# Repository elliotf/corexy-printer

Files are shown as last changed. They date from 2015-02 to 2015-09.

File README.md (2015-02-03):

# corexy-printer

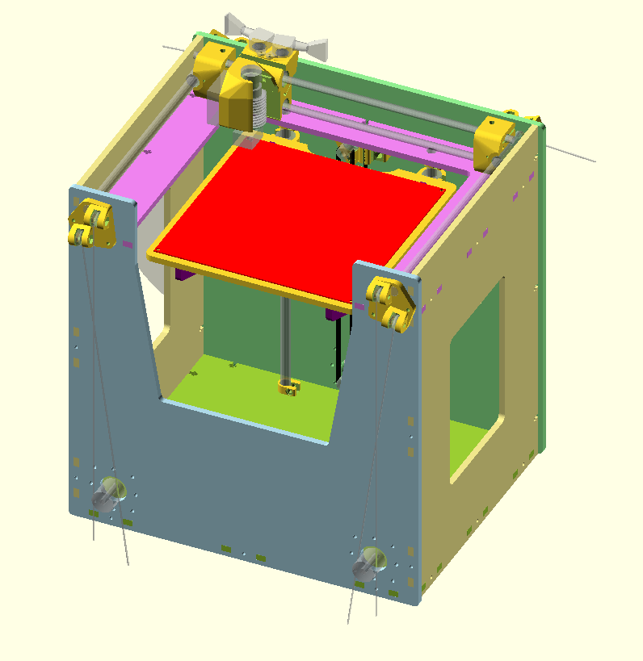
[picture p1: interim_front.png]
rendered picture of printer


An attempt at a compact, flexible, parametric corexy printer design that can be almost entirely lasercut.

The printer at http://audiots.wordpress.com is beautiful and inspired me to create a more unique take on the coreXY reference implementation.

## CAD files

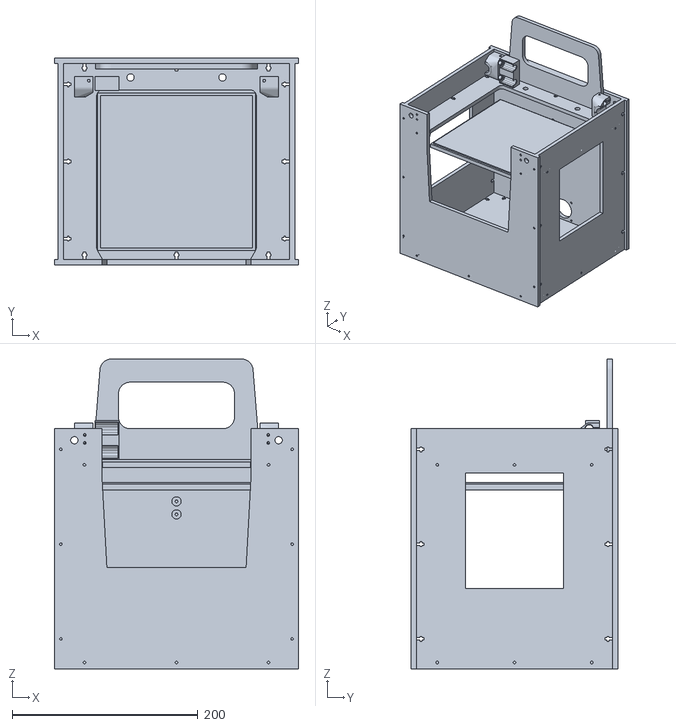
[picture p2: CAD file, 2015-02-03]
assembly.stl
263.0 x 223.1 x 333.9

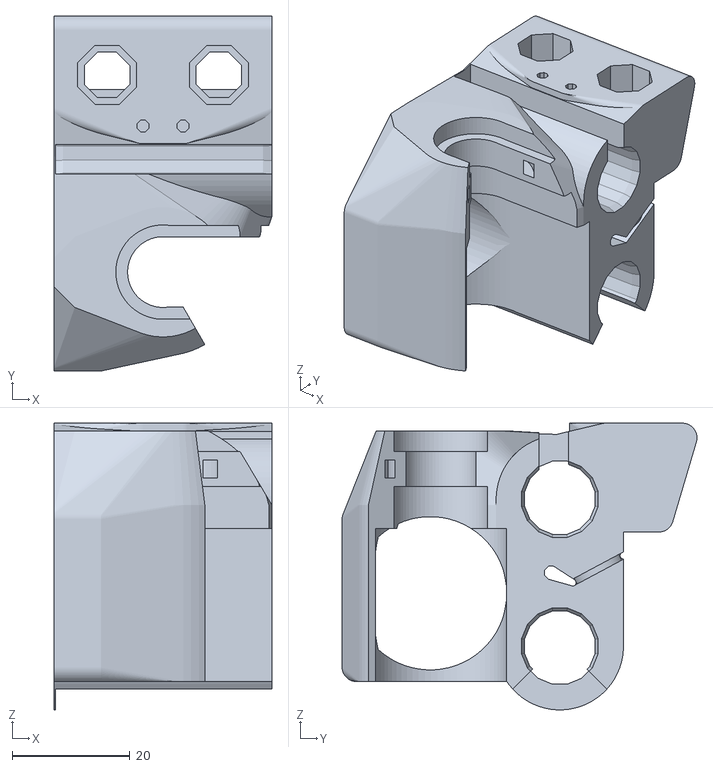
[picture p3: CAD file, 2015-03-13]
parts/x-carriage.stl
37.0 x 60.3 x 48.7

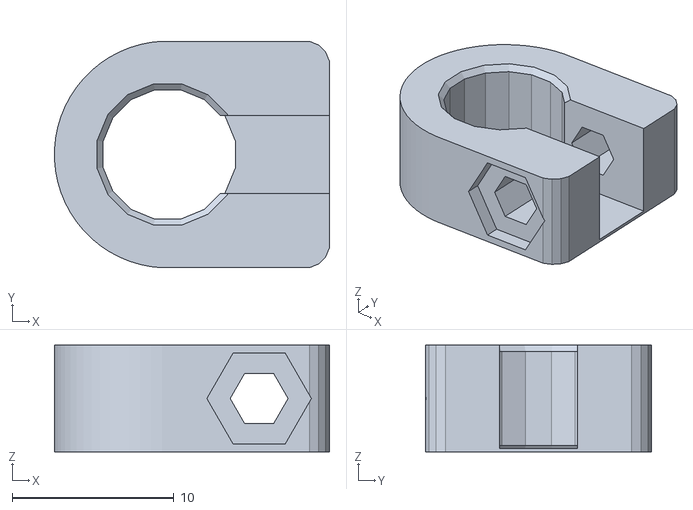
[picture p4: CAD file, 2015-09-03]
rod_clamp.stl
17.0 x 14.0 x 6.60

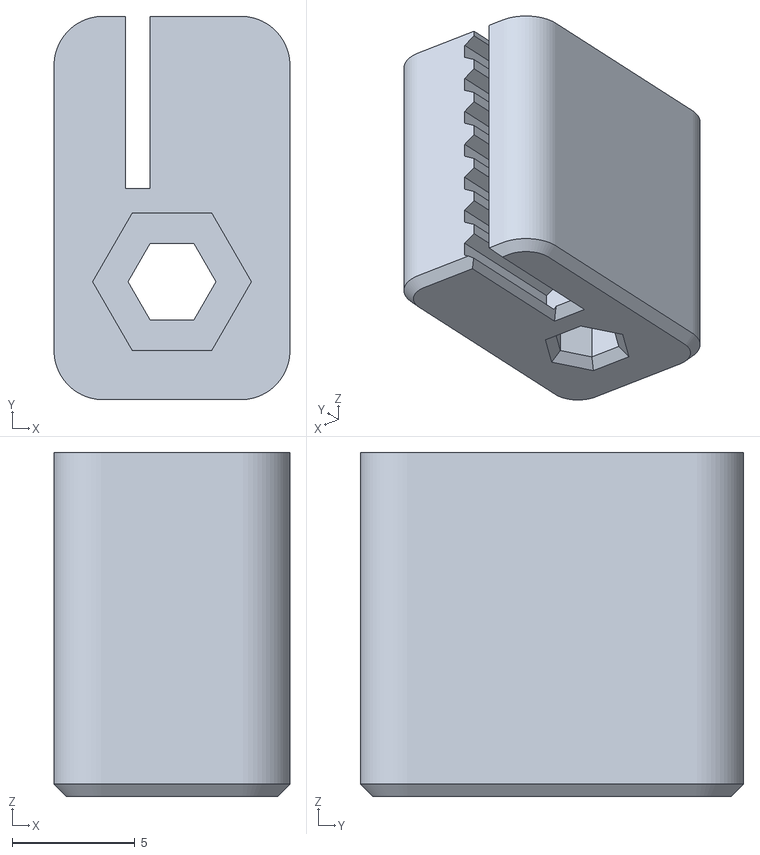
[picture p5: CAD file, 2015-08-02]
belt_tensioner.stl
9.60 x 15.6 x 14.0

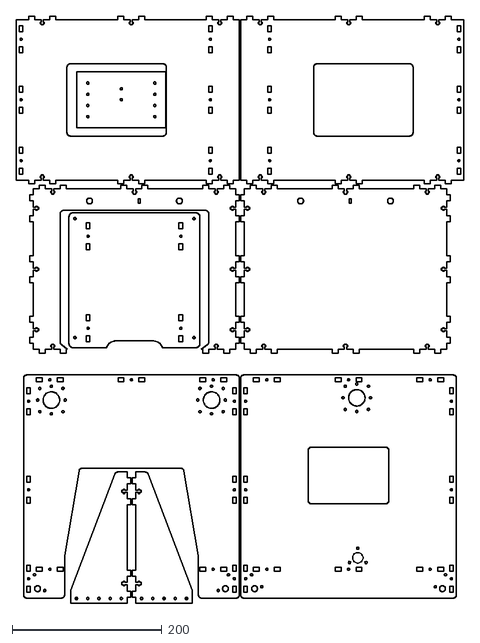
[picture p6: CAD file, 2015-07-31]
laser_cut_sheets.dxf
597.9 x 784.1

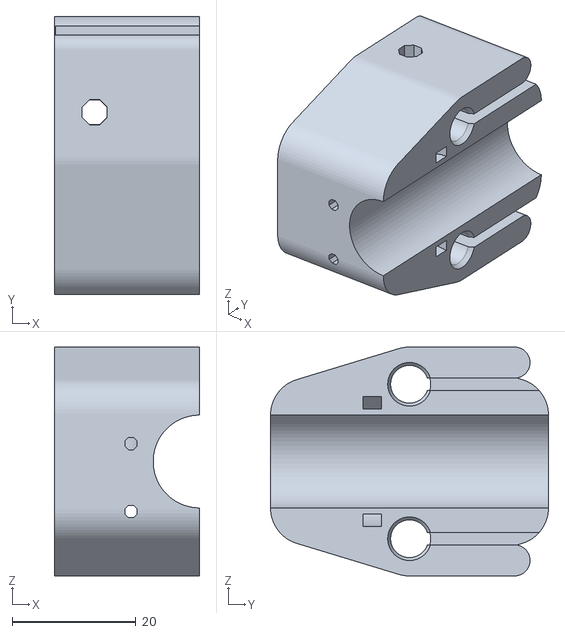
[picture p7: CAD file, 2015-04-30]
y_end.stl
23.5 x 45.0 x 37.0

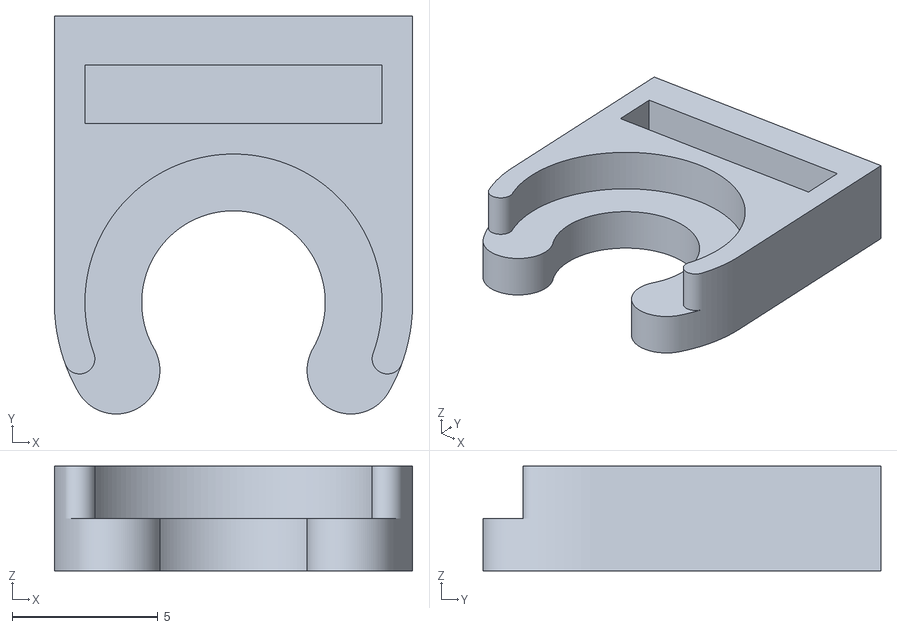
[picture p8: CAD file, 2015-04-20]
bowden_clip-1.75mm-1_8mm.stl
12.3 x 13.7 x 3.60

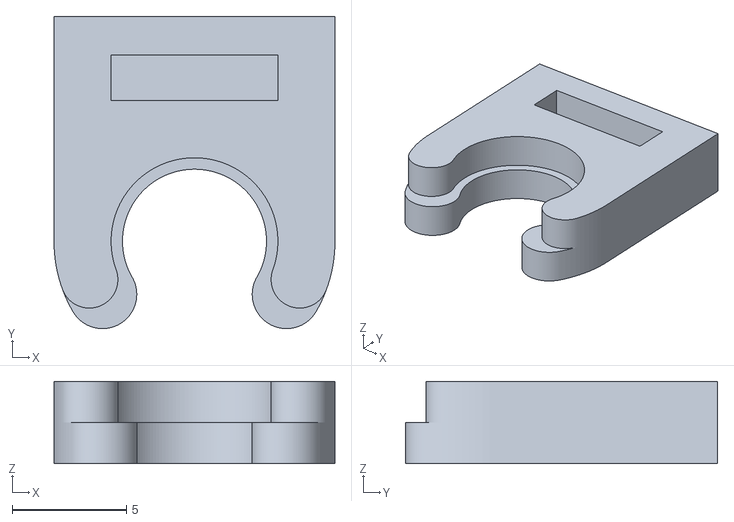
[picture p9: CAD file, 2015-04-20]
bowden_clip-1.75mm-1_8mm-narrow-collar.stl
12.3 x 13.7 x 3.60

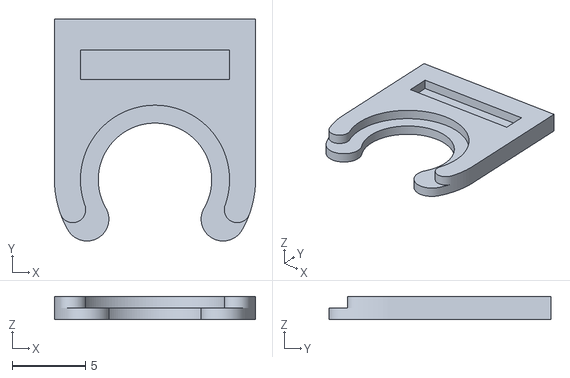
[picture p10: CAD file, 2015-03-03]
e3d-v6-3mm-bowden-clip-0_8mm.stl
13.8 x 15.2 x 1.60

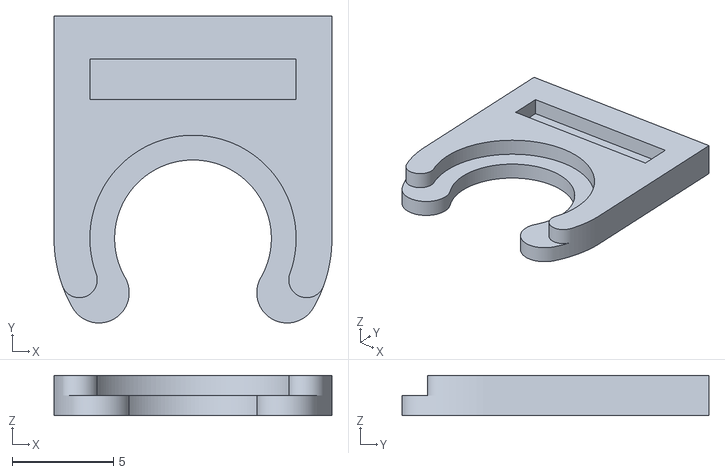
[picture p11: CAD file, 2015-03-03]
e3d-v6-3mm-bowden-clip-1_0mm.stl
13.8 x 15.2 x 2.00

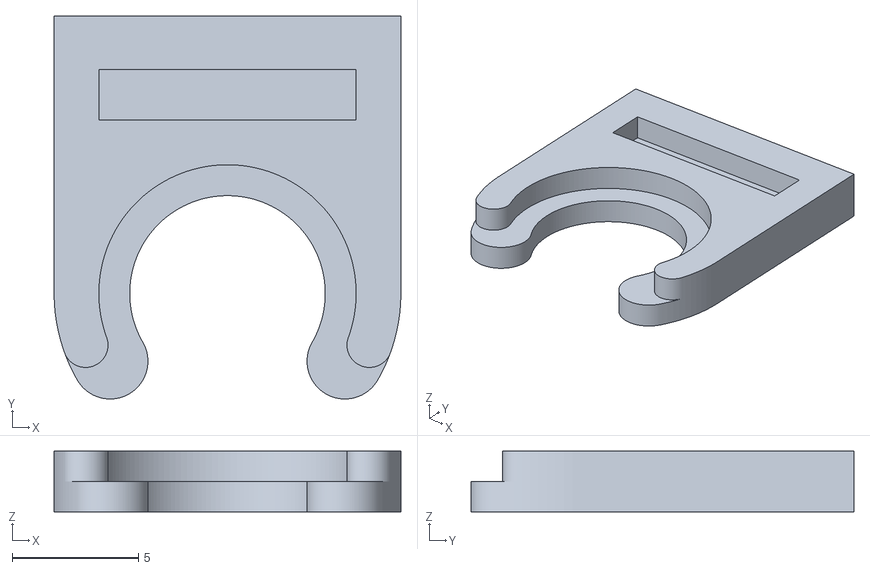
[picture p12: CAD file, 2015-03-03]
e3d-v6-3mm-bowden-clip-1_2mm.stl
13.8 x 15.2 x 2.40

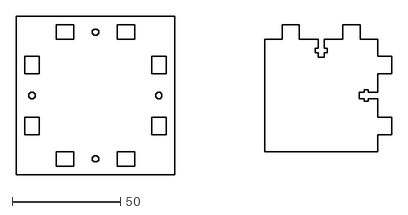
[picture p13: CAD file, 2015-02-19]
laser_cutter_calibration.dxf
173.0 x 73.0

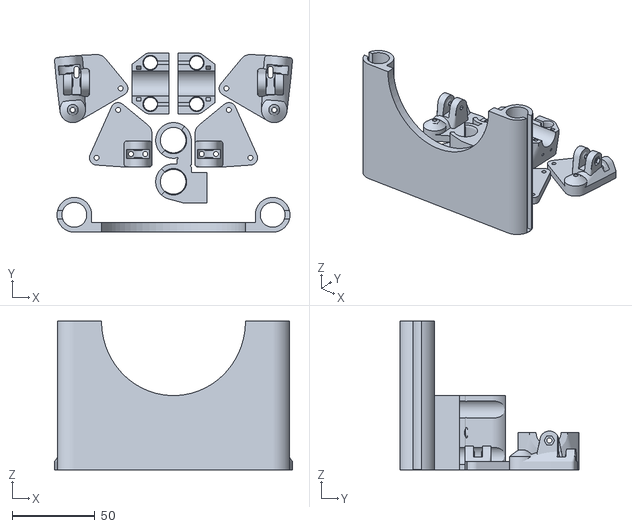
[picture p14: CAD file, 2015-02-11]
print_plate.stl
144.0 x 108.5 x 90.0

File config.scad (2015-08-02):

// All hail whosawhatsis
da6 = 1 / cos(180 / 6) / 2;
da8 = 1 / cos(180 / 8) / 2;

// Screws, nuts
m3_diam = 3.1;
m3_nut_diam  = 5.5 + 0.1;
m3_nut_thickness  = 4;
m3_washer_thickness  = .6;

m5_diam = 5;
m5_nut_diam = 8;
m5_nut_thickness = 5;
m5_washer_thickness  = 1;

m4_diam = 4;
m4_nut_diam = 7;
m4_nut_thickness = 4.5;
m4_washer_thickness  = 1;

bearing_625_diam      = 16;
bearing_625_inner     = 5;
bearing_625_thickness = 5;

approx_pi = 3.14159265359;

laser_cut_kerf = 0.06;

filament_spool_mount_spacer = 4;
filament_spool_inner_diam   = 53;
filament_spool_core_diam    = 93;
filament_spool_outer_diam   = 200;
filament_spool_width        = 71;

// make coordinates more communicative
left    = -1;
right   = 1;
front   = -1;
rear    = 1;
top     = 1;
bottom  = -1;

x = 0;
y = 1;
z = 2;

resolution = 16;
resolution = 64;

extrusion_width  = 0.5;
extrusion_height = 0.2;
min_material_thickness = extrusion_width*2;
wall_thickness         = extrusion_width*4;
rounded_diam           = 4;

// material dimensions
zip_tie_width = 3;
zip_tie_thickness = 2;
line_diam = .5;
line_cube = [line_diam,line_diam,line_diam];

// Printer size
build_x = 200;
build_y = 200;
build_z = 200;

build_x = 150;
build_y = 150;
build_z = 150;

z_belt_clamp_width = 14;

/*
build_x = 100;
build_y = 50;
build_z = 25;

build_x = 100;
build_y = 100;
build_z = 100;
*/

belt_total_thickness = 1.38;
belt_tooth_depth     = 0.75;
belt_thickness       = belt_total_thickness - belt_tooth_depth;
belt_thickness       = 1;
belt_width           = 6; // FIXME: make correct

belt_tooth_pitch   = 2;
num_teeth_to_clamp = 7;
belt_clamp_depth   = belt_width + m3_nut_diam + wall_thickness*1.5 + 1;
belt_clamp_width   = m3_nut_diam + wall_thickness*2;
belt_clamp_height  = num_teeth_to_clamp*belt_tooth_pitch;
z_belt_anchor_height       = belt_clamp_height*1.5;
z_belt_anchor_hole_spacing = z_belt_anchor_height/2;

z_idler_pulley_bearing_retainer_rim_thickness     = 1;
z_idler_pulley_bearing_retainer_thickness         = bearing_625_thickness + z_idler_pulley_bearing_retainer_rim_thickness;

filament_diam = 3;

hotend_diam                = 16;
hotend_groove_diam         = 12;
hotend_groove_height       = 4.6;
hotend_height_above_groove = 5;
hotend_len                 = 63;
hotend_clamped_height      = hotend_groove_height + hotend_height_above_groove;
hotend_len_below_groove    = hotend_len - hotend_clamped_height;
hotend_clearance   = 0.15;

// jhead
hotend_height_above_groove = 4.8;
hotend_groove_height = 4.6;

// e3d v6
hotend_height_above_groove = 3.7;
hotend_groove_height = 6;

// e3d v6 bowden heatsink mount
hotend_len                 = 65;
hotend_height_above_groove = 7;
hotend_height_below_groove = 3;
hotend_groove_height = 6;
hotend_diam = 22.4;
hotend_heatsink_diam = 22.4;
hotend_nozzle_to_bottom_fin = 20;
hotend_nozzle_to_top_fin = 46;
hotend_heatsink_height = 26;
hotend_dist_to_heatsink_bottom = 46;
hotend_dist_to_heatsink_top = hotend_dist_to_heatsink_bottom - hotend_heatsink_height;
hotend_mount_diam  = 16;
hotend_groove_diam = 12;

tuner_hole_to_shoulder = 22.5;
wire_hole_diam = 2;

tuner_thin_diam = 6;
tuner_thin_len_past_hole = 5;
tuner_thin_len = tuner_hole_to_shoulder + tuner_thin_len_past_hole;
tuner_thin_pos = tuner_hole_to_shoulder/2-tuner_thin_len_past_hole/2;

thick_diam = 10;
thick_len = 10;
thick_pos = tuner_hole_to_shoulder-thick_len+thick_len/2;

tuner_body_diam = 15;
tuner_body_thickness = 9;
tuner_body_square_len = 10;
tuner_body_pos = -tuner_hole_to_shoulder-tuner_body_thickness/2;

tuner_anchor_screw_hole_thickness = 2;
tuner_anchor_screw_hole_diam = 2;
tuner_anchor_screw_hole_width = 2;
tuner_anchor_screw_hole_pos_x = tuner_body_pos+tuner_body_thickness/2-tuner_anchor_screw_hole_thickness/2;
tuner_anchor_screw_hole_pos_y = -tuner_body_diam/2;
tuner_anchor_screw_hole_pos_z = -tuner_body_diam/2;

// Linear bearings and rods
// should record bearing groove offset, depth, width

// lm10uu, M10 rods
lm10uu_bearing_diam = 19;
lm10uu_bearing_len  = 29;
lm10uu_bearing_groove_spacing = 0;
lm10uu_bearing_groove_width = 0;
lm10uu_bearing_groove_depth = 0;
lm10uu_rod_diam = 10;

// lm8uu, M8 rods
lm8uu_bearing_diam = 15;
lm8uu_bearing_len  = 24;
lm8uu_bearing_groove_spacing = 0;
lm8uu_bearing_groove_width = 0;
lm8uu_bearing_groove_depth = 0;
lm8uu_rod_diam = 8;

// lm8luu, M8 rods
lm8luu_bearing_diam = 15;
lm8luu_bearing_len  = 45;
lm8luu_bearing_groove_spacing = 0;
lm8luu_bearing_groove_width = 0;
lm8luu_bearing_groove_depth = 0;
lm8luu_rod_diam = 8;

// bronze bushings, M8 rods
bronze_bearing_diam = 12;
bronze_bearing_len  = 15;
//bronze_bearing_len  = 30;
bronze_bearing_groove_spacing = 0;
bronze_bearing_groove_width = 0;
bronze_bearing_groove_depth = 0;
bronze_rod_diam = 8;

// lm6uu, M6 rods
lm6uu_bearing_diam = 12;
lm6uu_bearing_len  = 19;
lm6uu_bearing_groove_spacing = 12.25;
lm6uu_bearing_groove_width = .5;
lm6uu_bearing_groove_depth = .2;
lm6uu_rod_diam = 6;

// lm6luu, M6 rods
lm6luu_bearing_diam = 12;
lm6luu_bearing_len  = 35;
lm6luu_bearing_groove_spacing = 12.25;
lm6luu_bearing_groove_width = .5;
lm6luu_bearing_groove_depth = .2;
lm6luu_rod_diam = 6;

// graphite bearings from robotdigg
graphite_bronze_bearing_diam = 11;
graphite_bronze_bearing_len  = 30;
graphite_bronze_bearing_groove_spacing = 0;
graphite_bronze_bearing_groove_width = 0;
graphite_bronze_bearing_groove_depth = 0;
graphite_bronze_rod_diam = 8;

bearing_diam           = lm10uu_bearing_diam;
bearing_len            = lm10uu_bearing_len;
bearing_groove_spacing = lm10uu_bearing_groove_spacing;
bearing_groove_width   = lm10uu_bearing_groove_width;
bearing_groove_depth   = lm10uu_bearing_groove_depth;
rod_diam               = lm10uu_rod_diam;

bearing_diam           = lm8uu_bearing_diam;
bearing_len            = lm8uu_bearing_len;
bearing_groove_spacing = lm8uu_bearing_groove_spacing;
bearing_groove_width   = lm8uu_bearing_groove_width;
bearing_groove_depth   = lm8uu_bearing_groove_depth;
rod_diam               = lm8uu_rod_diam;

/*
bearing_diam           = bronze_bearing_diam;
bearing_len            = bronze_bearing_len;
bearing_groove_spacing = bronze_bearing_groove_spacing;
bearing_groove_width   = bronze_bearing_groove_width;
bearing_groove_depth   = bronze_bearing_groove_depth;
rod_diam               = bronze_rod_diam;

bearing_diam           = lm6uu_bearing_diam;
bearing_len            = lm6uu_bearing_len;
bearing_groove_spacing = lm6uu_bearing_groove_spacing;
bearing_groove_width   = lm6uu_bearing_groove_width;
bearing_groove_depth   = lm6uu_bearing_groove_depth;
rod_diam               = lm6uu_rod_diam;
*/

// if you'd like the x axis to use different rods/bearings
x_bearing_diam           = lm8luu_bearing_diam;
x_bearing_len            = lm8luu_bearing_len;
x_bearing_groove_spacing = lm8luu_bearing_groove_spacing;
x_bearing_groove_width   = lm8luu_bearing_groove_width;
x_bearing_groove_depth   = lm8luu_bearing_groove_depth;
x_rod_diam               = lm8luu_rod_diam;

x_bearing_diam           = lm8uu_bearing_diam;
x_bearing_len            = lm8uu_bearing_len;
x_bearing_groove_spacing = lm8uu_bearing_groove_spacing;
x_bearing_groove_width   = lm8uu_bearing_groove_width;
x_bearing_groove_depth   = lm8uu_bearing_groove_depth;
x_rod_diam               = lm8uu_rod_diam;

x_bearing_diam           = lm6uu_bearing_diam;
x_bearing_len            = lm6uu_bearing_len;
x_bearing_groove_spacing = lm6uu_bearing_groove_spacing;
x_bearing_groove_width   = lm6uu_bearing_groove_width;
x_bearing_groove_depth   = lm6uu_bearing_groove_depth;
x_rod_diam               = lm6uu_rod_diam;

x_bearing_diam           = lm6luu_bearing_diam;
x_bearing_len            = lm6luu_bearing_len;
x_bearing_groove_spacing = lm6luu_bearing_groove_spacing;
x_bearing_groove_width   = lm6luu_bearing_groove_width;
x_bearing_groove_depth   = lm6luu_bearing_groove_depth;
x_rod_diam               = lm6luu_rod_diam;

/*
// if you'd like the x axis to use the default rods/bearings
x_bearing_diam           = bearing_diam;
x_bearing_len            = bearing_len;
x_bearing_groove_spacing = bearing_groove_spacing;
x_bearing_groove_width   = bearing_groove_width;
x_bearing_groove_depth   = bearing_groove_depth;
x_rod_diam               = rod_diam;
*/

// y bearings
y_bearing_diam           = lm8luu_bearing_diam;
y_bearing_len            = lm8luu_bearing_len;
y_bearing_groove_spacing = lm8luu_bearing_groove_spacing;
y_bearing_groove_width   = lm8luu_bearing_groove_width;
y_bearing_groove_depth   = lm8luu_bearing_groove_depth;
y_rod_diam               = lm8luu_rod_diam;

// y bearings
y_bearing_diam           = graphite_bronze_bearing_diam;
y_bearing_len            = graphite_bronze_bearing_len;
y_bearing_groove_spacing = graphite_bronze_bearing_groove_spacing;
y_bearing_groove_width   = graphite_bronze_bearing_groove_width;
y_bearing_groove_depth   = graphite_bronze_bearing_groove_depth;
y_rod_diam               = graphite_bronze_rod_diam;
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

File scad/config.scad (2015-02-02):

// All hail whosawhatsis
da6 = 1 / cos(180 / 6) / 2;
da8 = 1 / cos(180 / 8) / 2;

approx_pi = 3.14159;

laser_cut_kerf = 0.06;

// make coordinates more communicative
left    = -1;
right   = 1;
front   = -1;
rear    = 1;
top     = 1;
bottom  = -1;

x = 0;
y = 1;
z = 2;

resolution = 16;
resolution = 64;

extrusion_width  = 0.5;
extrusion_height = 0.3;

// material dimensions
zip_tie_width = 3;
zip_tie_thickness = 2;
line_diam = .5;
line_cube = [line_diam,line_diam,line_diam];

// Printer size
build_x = 200;
build_y = 200;
build_z = 200;

build_x = 150;
build_y = 150;
build_z = 150;

/*
build_x = 100;
build_y = 100;
build_z = 100;
*/

belt_thickness = 0.5; // FIXME: make correct
belt_width     = 6; // FIXME: make correct

hotend_diam                = 16;
hotend_groove_diam         = 12;
hotend_groove_height       = 4.6;
hotend_height_above_groove = 5;
hotend_len                 = 63;
hotend_clamped_height      = hotend_groove_height + hotend_height_above_groove;
hotend_len_below_groove    = hotend_len - hotend_clamped_height;

// Linear bearings and rods
// should record bearing groove offset, depth, width

// lm10uu, M10 rods
lm10uu_bearing_diam = 19;
lm10uu_bearing_len  = 29;
lm10uu_bearing_groove_spacing = 0;
lm10uu_bearing_groove_width = 0;
lm10uu_bearing_groove_depth = 0;
lm10uu_rod_diam = 10;

// lm8uu, M8 rods
lm8uu_bearing_diam = 15;
lm8uu_bearing_len  = 24;
lm8uu_bearing_groove_spacing = 0;
lm8uu_bearing_groove_width = 0;
lm8uu_bearing_groove_depth = 0;
lm8uu_rod_diam = 8;

// lm8luu, M8 rods
lm8luu_bearing_diam = 15;
lm8luu_bearing_len  = 45;
lm8luu_bearing_groove_spacing = 0;
lm8luu_bearing_groove_width = 0;
lm8luu_bearing_groove_depth = 0;
lm8luu_rod_diam = 8;

// bronze bushings, M8 rods
bronze_bearing_diam = 12;
bronze_bearing_len  = 15;
//bronze_bearing_len  = 30;
bronze_bearing_groove_spacing = 0;
bronze_bearing_groove_width = 0;
bronze_bearing_groove_depth = 0;
bronze_rod_diam = 8;

// lm6uu, M6 rods
lm6uu_bearing_diam = 12;
lm6uu_bearing_len  = 19;
lm6uu_bearing_groove_spacing = 12.25;
lm6uu_bearing_groove_width = .5;
lm6uu_bearing_groove_depth = .2;
lm6uu_rod_diam = 6;

bearing_diam           = lm10uu_bearing_diam;
bearing_len            = lm10uu_bearing_len;
bearing_groove_spacing = lm10uu_bearing_groove_spacing;
bearing_groove_width   = lm10uu_bearing_groove_width;
bearing_groove_depth   = lm10uu_bearing_groove_depth;
rod_diam               = lm10uu_rod_diam;

bearing_diam           = lm8uu_bearing_diam;
bearing_len            = lm8uu_bearing_len;
bearing_groove_spacing = lm8uu_bearing_groove_spacing;
bearing_groove_width   = lm8uu_bearing_groove_width;
bearing_groove_depth   = lm8uu_bearing_groove_depth;
rod_diam               = lm8uu_rod_diam;

/*
bearing_diam           = bronze_bearing_diam;
bearing_len            = bronze_bearing_len;
bearing_groove_spacing = bronze_bearing_groove_spacing;
bearing_groove_width   = bronze_bearing_groove_width;
bearing_groove_depth   = bronze_bearing_groove_depth;
rod_diam               = bronze_rod_diam;

bearing_diam           = lm6uu_bearing_diam;
bearing_len            = lm6uu_bearing_len;
bearing_groove_spacing = lm6uu_bearing_groove_spacing;
bearing_groove_width   = lm6uu_bearing_groove_width;
bearing_groove_depth   = lm6uu_bearing_groove_depth;
rod_diam               = lm6uu_rod_diam;
*/

// if you'd like the z axis to use different rods/bearings
z_bearing_diam           = lm8uu_bearing_diam;
z_bearing_len            = lm8uu_bearing_len;
z_bearing_groove_spacing = lm8uu_bearing_groove_spacing;
z_bearing_groove_width   = lm8uu_bearing_groove_width;
z_bearing_groove_depth   = lm8uu_bearing_groove_depth;
z_rod_diam               = lm8uu_rod_diam;

z_bearing_diam           = lm8luu_bearing_diam;
z_bearing_len            = lm8luu_bearing_len;
z_bearing_groove_spacing = lm8luu_bearing_groove_spacing;
z_bearing_groove_width   = lm8luu_bearing_groove_width;
z_bearing_groove_depth   = lm8luu_bearing_groove_depth;
z_rod_diam               = lm8luu_rod_diam;

/*
z_bearing_diam           = bearing_diam;
z_bearing_len            = bearing_len;
z_bearing_groove_spacing = bearing_groove_spacing;
z_bearing_groove_width   = bearing_groove_width;
z_bearing_groove_depth   = bearing_groove_depth;
z_rod_diam               = rod_diam;
*/

rod_slop = 0.1;

// endstop dimensions
endstop_len = 20;
endstop_width = 6;
endstop_height = 8;
endstop_hole_spacing = 10;
endstop_hole_diam = 2;
endstop_hole_from_top = 5;

// Screws, nuts
m3_diam = 3;
m3_nut_diam  = 5.5;
m3_nut_thickness  = 3;
m3_washer_thickness  = .6;
m5_diam = 5;
m5_nut_diam = 8;
m5_nut_thickness = 5;
m5_washer_thickness  = 1;

// Groove bearings
// 625s
belt_bearing_diam = 15;
belt_bearing_groove_depth = .5;
belt_bearing_inner = m5_diam;
belt_bearing_thickness = 5;
belt_bearing_nut_diam = m5_nut_diam;
belt_bearing_nut_thickness = m5_nut_thickness;
belt_bearing_washer_thickness = m5_washer_thickness;

// 623vv
/*
*/
belt_bearing_diam = 12;
belt_bearing_groove_depth = 1.7;
belt_bearing_inner = m3_diam;
belt_bearing_thickness = 4;
belt_bearing_nut_diam = m3_nut_diam;
belt_bearing_nut_thickness = m3_nut_thickness;
belt_bearing_washer_thickness = m3_washer_thickness;

belt_bearing_effective_diam = belt_bearing_diam - (belt_bearing_groove_depth*2);

pulley_idler_bearing_diam = 16;
pulley_idler_bearing_inner = 5;
pulley_idler_bearing_thickness = 5;

// Motor
nema17_side = 43;
nema17_len = nema17_side;
nema17_hole_spacing = 31;
nema17_shoulder_diam = 22;
nema17_screw_diam = m3_diam;
nema17_shaft_diam = 5;
nema17_shaft_len = 24;

nema14_side = 35.3;
nema14_len = nema14_side;
nema14_hole_spacing = 26;
nema14_shoulder_diam = 22;
nema14_screw_diam = m3_diam;
nema14_shaft_diam = 5;
nema14_shaft_len = 20;

motor_side = nema17_side;
motor_len = motor_side;
motor_hole_spacing = nema17_hole_spacing;
motor_shoulder_diam = nema17_hole_spacing;
motor_screw_diam = nema17_screw_diam;
motor_shaft_diam = nema17_shaft_diam;
motor_shaft_len = nema17_shaft_len;
motor_wire_hole_width = 9;
motor_wire_hole_height = 6;

z_motor_side = nema14_side;
z_motor_len = z_motor_side;
z_motor_hole_spacing = nema14_hole_spacing;
z_motor_shoulder_diam = nema14_hole_spacing;
z_motor_screw_diam = nema14_screw_diam;
z_motor_shaft_diam = nema14_shaft_diam;
z_motor_shaft_len = nema14_shaft_len;

z_motor_side = nema17_side;
z_motor_len = z_motor_side;
z_motor_hole_spacing = nema17_hole_spacing;
z_motor_shoulder_diam = nema17_hole_spacing;
z_motor_screw_diam = nema17_screw_diam;
z_motor_shaft_diam = nema17_shaft_diam;
z_motor_shaft_len = nema17_shaft_len;

// Frame sheet
sheet_thickness = 6;
sheet_min_width = 30;
sheet_shoulder_width = 3; // material to have on the far side of a slot
sheet_screw_diam = m3_diam;
sheet_screw_nut_diam = m3_nut_diam;
sheet_screw_nut_thickness = m3_nut_thickness;
sheet_hole_resolution = resolution;

top_plate_screw_diam = sheet_screw_diam;

// Misc settings
min_material_thickness = 1;
spacer = 1;
clamp_gap_width = spacer;
screw_pad_height = min_material_thickness*2;
screw_pad_outer_diam = top_plate_screw_diam+min_material_thickness*3;
screw_pad_hole_spacing = (rod_diam/2 + min_material_thickness*3 + top_plate_screw_diam/2) * 2;
screw_pad_width = screw_pad_hole_spacing + (top_plate_screw_diam/2 + min_material_thickness*2) * 2;

// Screws
clamp_screw_diam = m3_diam;
clamp_screw_nut_diam = m3_nut_diam;
clamp_screw_nut_thickness = m3_nut_thickness;
clamp_area_width = clamp_screw_diam+min_material_thickness*2;

// Printer settings
y_clamp_len = 10; // amount of bar to clamp onto
x_rod_spacing = bearing_diam + min_material_thickness * 2;
x_carriage_width = bearing_len * 2 + 10 + min_material_thickness*4;
x_carriage_width = bearing_len * 2 + min_material_thickness*3;
x_carriage_depth = x_rod_spacing + bearing_diam;

// calculated rod lengths
//x_rod_len = build_x + x_carriage_width + belt_bearing_diam*2 + min_material_thickness;
//y_rod_len = build_y + x_rod_spacing + rod_diam + min_material_thickness*2;
//x_rod_len = 270; // have avail
//y_rod_len = 265; // have avail

// tuner dimensions (pull out into a different file)
tuner_shoulder_width = 10;
tuner_shoulder_diam  = 10;
tuner_shaft_diam     = 6;
tuner_hole_to_shoulder = 22.5;
tensioner_angle = 45;

// Power supply
psu_length = 215;
psu_width = 114;
psu_height = 50;

// Pulley
pulley_diam = 20;
pulley_diam = 40/approx_pi; // 32 =~ 16T GT2, 40 =~ 20T GT2
pulley_height = belt_bearing_diam;
pulley_height = 13;

pulley_idler_height = pulley_height;
pulley_idler_diam = pulley_idler_bearing_diam + min_material_thickness*2;
pulley_idler_shaft_diam = m5_diam;
pulley_idler_shaft_nut_diam = m5_nut_diam;
pulley_idler_shaft_nut_thickness = m5_nut_thickness;
pulley_idler_shaft_support_len = pulley_height;

// heated bed / build plate
heatbed_thickness = 1;
heatbed_hole_spacing_x = build_x+9;
heatbed_hole_spacing_y = build_y+9;
heatbed_hole_diam = 3;
heatbed_width = build_x+14;
heatbed_depth = build_y+14;

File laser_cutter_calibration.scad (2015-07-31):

include <config.scad>;
include <positions.scad>;
include <boxcutter.scad>;
use <util.scad>;

box_side_len = bc_tab_from_end_dist * 2 + bc_tab_slot_pair_len;

/*
//projection(cut=true) {
  translate([0,box_side_len,0]) {
    for(side=[left,right]) {
      mirror([1-side,0,0]) {
        translate([box_side_len*2.75,0,0]) {
          difference() {
            box_side([box_side_len*2,box_side_len*1],[3,3,3,3]);

            translate([-box_side_len*1,0,0]) {
              for(x=[1:7]) {
                translate([rod_diam*1+rod_diam*1.35*x,rod_diam,0]) {
                  hole(rod_diam-0.02*x,sheet_thickness+1,resolution);

                }
                translate([rod_diam*1+rod_diam*1.35*x,-rod_diam,0]) {
                  hole(rod_diam-0.02*x,sheet_thickness+1,x*2);
                }
              }
            }
          }
        }
      }
    }
  }
  translate([0,-box_side_len,0]) {
    for(side=[left,right]) {
      translate([box_side_len*2.75*side,0,0]) {
        box_side([box_side_len*2,box_side_len*1],[4,3,4,3]);
      }
    }
  }

  for(side=[left,right]) {
    translate([0,box_side_len*side,0]) {
      box_side([box_side_len*1,box_side_len*1],[4,4,4,4]);
    }
  }
//}
*/

translate([box_side_len*left,0,0]) {
  box_side([box_side_len*1,box_side_len*1],[4,4,4,4]);
}
translate([box_side_len*right,0,0]) {
  box_side([box_side_len*1,box_side_len*1],[3,0,0,3]);
}

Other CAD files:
assembly.scad
belt_retainer.scad
bowden_clip.scad
boxcutter.scad
debug.scad
laser_cut_sheets.scad
main.scad
positions.scad
print_plate.scad
scad/main.scad
scad/plate.scad
scad/positions.scad
scad/util.scad
util.scad

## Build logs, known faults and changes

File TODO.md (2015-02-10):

# TODO

* z carriage
* endstop mounting
* compensate for spectra line diameter

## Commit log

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2013-09-27 Make main.scad clean to allow inclusion in other files
    [assembly.scad, main.scad, plate.scad]
2013-09-27 Correct transparency of rods
    [assembly.scad]
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2013-09-28 Make rear plate solid, print max plate size
    [assembly.scad, main.scad]
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2013-09-29 Correct misplaced rod clamp on plates
    [plate.scad]
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2013-09-29 Fix rod clamp position typo in assembly
    [assembly.scad]
2013-09-29 Reduce print overhangs, line rubbing on screw head
    [main.scad]
2013-09-30 An experimental pulley system.
    Inspired by:
    http://3dprinterhell.blogspot.com/2013/06/a-better-filament-drive.html
    I'll print this out once I get my spectra line and see how it goes.
    [pulley.scad]
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2013-09-30 Have y ends anchor into sheets if possible
    [assembly.scad, main.scad]
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2013-10-01 Bearing len != diam, correct belt bearing effective diam
    [main.scad]
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2013-10-01 Avoid stray cruft on x carriage due to zip ties
    [main.scad]
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2013-10-01 An idea to reduce the mass of the x carriage
    If the guitar machines are too heavy, the design could be reworked to
    use just one for both lines.
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2013-10-02 Move motors out to make room for PSU
    [assembly.scad, config.scad, positions.scad]
2013-10-02 Default to 8x8x8 size
    Start paying attention to rod lengths. It looks like 8x8x8 should be
    doable with huxley-length smooth rods.
    [config.scad, main.scad]
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2013-10-02 Endstop only on negative side of y carriage
    [assembly.scad, main.scad]
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2013-10-05 New x carriage, work on z axis
    World's messiest commit.
    [assembly.scad, config.scad, jhead.scad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]
2013-10-06 sketching out ideas for Z axis
    The centrally supported z axis is more scalable (a 12x12 or 24x24
    printer would require quite the z rod and vertical bracing). We'll see
    if the linear bearings are stable enough. Cheap bearings might rock more
    than desired. Maybe use three bearings or use lm8uu for Z even on the
    m6-size printer?
    [assembly.scad, config.scad, main.scad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]
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2013-10-06 Correct y carriage z on build plate
    [main.scad, plate.scad]
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2013-10-06 M8,M10 fits inside 200x200
    However, the new X carriage is b0rked for anything larger than M6.
    [plate.scad]
2013-10-06 New plate STLs, b0rked though they may be
    [m10_gantry.stl, m6_gantry.stl, m8_gantry.stl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]
2013-10-07 Correct y endstop position
    [main.scad]
2013-10-07 Front y end has clamp
    Hopefully this will make it easier to spin the smooth rod to quiet the
    bearings.
    [config.scad, main.scad]
2013-10-08 Blegh, but should commit progress
    World's messiest commit, but I ought to do so, and it's late.
    [assembly.scad, config.scad, main.scad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]
2013-10-08 Add line clearance to y carriage bottom
    [main.scad]
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2013-10-09 More fiddling with pulley
    One observation: with the current design, the pulley is probably too
    tall.
    [config.scad, main.scad, positions.scad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]
2013-10-09 Reduce overhang angles to make easier to print
    [main.scad]
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2013-10-09 MOAR BLOCKY y end rear, simpler, easier to print
    [main.scad]
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2013-10-11 Another big commit. San pandas.
    Got rid of lower rear idler; motor pulley fulfills that role
    [assembly.scad, config.scad, main.scad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]
2013-10-11 Add shaft support to pulley
    Pulley is likely way too tall. Maybe add shaft support, or try a
    different design?
    [pulley.scad]
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2013-10-14 No odd angles, but a lot of line rubbing
    [full_lasercut.scad]
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2013-10-16 Attempt to make easier to print
    Reduce overhang angle and make groove spaces taller and spaced farther
    apart
    [pulley.scad]
2013-10-16 Try an idler on a shaft that is on bearings
    The idler can be on a shaft that rides on bearings, rather than
    having bearings inside the idler.
    This allows for a smaller diameter idler.
    [pulley.scad]
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2013-10-16 Correct paths to included files
    [z_axis.scad]
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2013-10-18 Rear idlers, and avoid line rubbing
    [assembly.scad, config.scad, main.scad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]
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2013-10-18 Make top opening larger
    Should hopefully be able to use the top opening as the bed support plate
    [positions.scad]
2013-10-18 New motor and idler line pulleys
    Created using additive means, which seems to prevent visual defects in openscad
    when designing
    [pulley.scad]
2013-10-18 Make STL printable
    Objects were in mid-air, which would make them tricky to print
    [pulley.scad]
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2014-10-18 Dimensions for short bronze bushings
    [config.scad]
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2015-02-01 Ease bed tolerances to make success more likely
    [simpler.scad]
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2015-02-01 Use correct shaft length
    [config.scad]
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2015-02-03 Out with the old, in with the new
    I like the direction of the new code, so let's commit to it.
    [assembly.scad, full_lasercut.scad, main.scad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]
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2015-02-03 Correct file contents with new directory structure
    [boxcutter.scad, positions.scad]
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2015-02-04 Provide wiggle room and use entire sheet of MDF
    Basically, make the box as big as can fit on the 24"x18" sheet of MDF
    [positions.scad, sheets.scad]
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2015-02-05 Rendering of box sides
    Not a DXF for now, because it's slow as hell to render
    [sheets.stl]
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2015-02-06 Correct angles for rear idlers
    [main.scad, positions.scad]
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2015-02-07 Belt bevel less likely to rub on the bearing
    [main.scad]
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2015-02-07 Fix top opening to make room for bed
    [boxcutter.scad, config.scad, main.scad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]
2015-02-07 I think I have the right opening calculation
    SRSLY, I think I do.
    [main.scad, positions.scad]
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2015-02-08 Starting on x carriage
    Commit before rearranging the z positions of lines to give more room to
    the tuner tensioners.
    [debug.scad, main.scad, positions.scad]
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2015-02-08 Distinguish between purpose and position
    So that we can shortly reassign positions by different purposes
    [main.scad, positions.scad]
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2015-02-10 More spaced-out tab support
    It would be nice to have more distance between the front/rear to side
    screw holes and the top to side tabs..
    [boxcutter.scad]
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2015-02-10 Tighter fit around rods
    [config.scad]
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2015-02-13 Reinforce holes with more perimeters/layers
    [main.scad]
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2015-02-28 An attempt to quiet the printer
    The large open sheets and hard coupling result in a bit of noise.
    [main.scad, positions.scad]
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2015-02-28 Speed up cut sheet rendering
    Don't bother with 3d => 2d, just start with 2d
    [boxcutter.scad, laser_cut_sheets.scad, main.scad]
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2015-02-28 Make it a little easier to separate later on
    If I need/want to move pieces around, provide a little more breathing
    room to select the bed piece
    [laser_cut_sheets.scad]
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2015-03-03 First pass at a clip for the bowden push-to-fit
    Otherwise it loosens when retracting/extruding/retracting/etc
    [bowden_clip.scad]
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2015-03-10 Provide room for flex around bearings
    [main.scad]
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2015-03-12 Likely don't need to add clearance here.
    [config.scad]
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2015-03-14 Avoid too-large holes on smaller sizes
    [assembly.scad, main.scad, positions.scad]
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2015-03-15 Print plate with z motor mount
    larger than 150x150 build volume, but that should be able to be fixed
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2015-04-20 A (hopefully) simpler and easier z axis
    Because man, that was not easy to feed the belts.
    [config.scad, main.scad, positions.scad]
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2015-04-20 Z carriage bearing arm is no longer laser cut
    [laser_cut_sheets.scad]
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2015-05-30 Simpler XY endcaps, corrected angles
    [assembly.scad, config.scad, main.scad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]
2015-05-30 An attempt to fix the rod clamp crampedness
    [main.scad]
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2015-05-30 Print plate fixed up
    [positions.scad, print_plate.scad]
2015-05-30 Rendering of fixed print plate
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2015-06-14 Correct bronze bushing diam
    [config.scad]
2015-06-14 Leave room for error/bearing switching
    [positions.scad]
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2015-06-14 Print plate additions/fixes
    [assembly.scad, belt_retainer.scad, config.scad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]
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2015-07-31 Pretty side of the rear is where people will see
    Pretty side faces down, and reorient the rear sheet so that the pretty
    side will face the viewer when assembled
    [assembly.scad, laser_cut_sheets.scad, positions.scad]
2015-07-31 16T pulley seems to work for Z idler pulley
    So, one fewer part type
    [assembly.scad, config.scad, positions.scad]
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2015-08-02 Example of problematic part with ABS
    [belt_tensioner.stl, debug.scad]
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2015-08-02 Fix missing motor-side-based calculations
    [assembly.scad, positions.scad]
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
